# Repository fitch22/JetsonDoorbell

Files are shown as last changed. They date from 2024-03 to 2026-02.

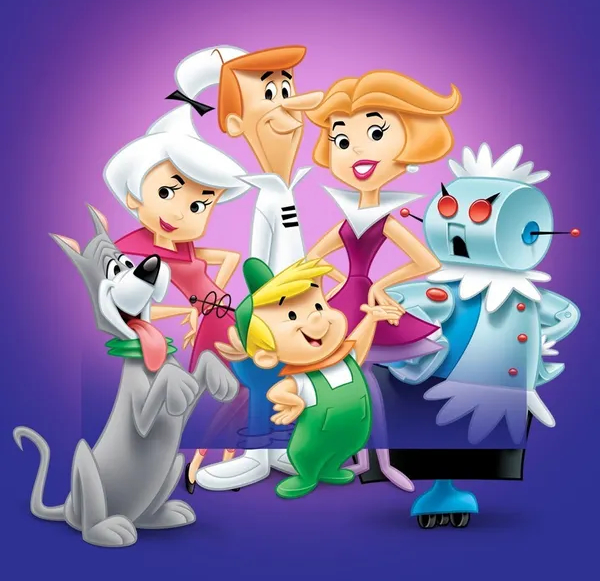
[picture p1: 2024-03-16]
web_root/background.jpg

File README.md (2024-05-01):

# The Jetson Doorbell

This repository has everything you need to get started with your Jetson Doorbell.
The [Getting Started](/fitch22/JetsonDoorbell/docs/GettingStarted.pdf) guide provides details on how to hook it up to replace standard mechanical chime doorbells as well as general operation and troubleshooting.
Several enclosure designs are provided that you can 3D print as is, or modify as necessary for your application.

## Where to find Doorbell Sounds

Here are some links to web sites that have sounds that work well for doorbells:  
[Orange FREE Sounds](https://orangefreesounds.com/)  
[Mixkit](https://mixkit.co/free-sound-effects/doorbell/)  
[Pixabay](https://pixabay.com/sound-effects/search/doorbell/)  
[Zapsplat](https://www.zapsplat.com/)  
Note, several of the sounds you will find to download are in MP3 format and must be converted to WAVE format before using with Jetson Doorbell.
You can convert an MP3 to a WAVE with an online converter such as:  
https://online-audio-converter.com/  
https://cloudconvert.com/audio-converter  
Or you can use an application such as [Audacity](https://www.audacityteam.org/). Audacity can do much more than convert, you can also adjust the tonal balance of the tune which can help with small, less than ideal speakers.

One tune you definitely want to get is the [Jetson's Doorbell](https://orangefreesounds.com/jetsons-doorbell/), just remember to convert it to a WAVE file.

## Building the Firmware

Jetson Doorbell uses an ESP32-S3-N4 module running at 240MHz.
The current version of firmware is 0.1.
It was built with ESP IDF 5.2.1 and uses Mongoose web server 7.13 using VSCODE and the ESP-IDF extension.
Information on how to install the ESP IDF as well as using VSCODE as a development environment can be found [here](https://docs.espressif.com/projects/esp-idf/en/stable/esp32s3/index.html).
Information on how to use the Mongoose web server can be found [here](https://mongoose.ws/).

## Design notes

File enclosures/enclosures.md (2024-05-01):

# Enclosures

In this folder you will find several example designs for enclosing your Jetson Doorbell and a speaker. Each file type has its original source in Solidworks format along with a STEP format and STL. You can print the STL file as is or modify the Solidworks or STEP file as you like.

These designs were all created for some speakers made by Visaton. The Visaton speaker model is part of the file name, for example FR10. I have no affiliation with Visaton, they just happen to make good, economical speakers.

Visaton also makes speaker grills that can be used with their speakers. You might find them more attractive than the 3D printed grills provided here.

For all the enclosures, the design uses M3x4x5 threaded inserts for attaching the lid.
The bosses for mounting the PCBs are expected to be tapped for M3 screws.

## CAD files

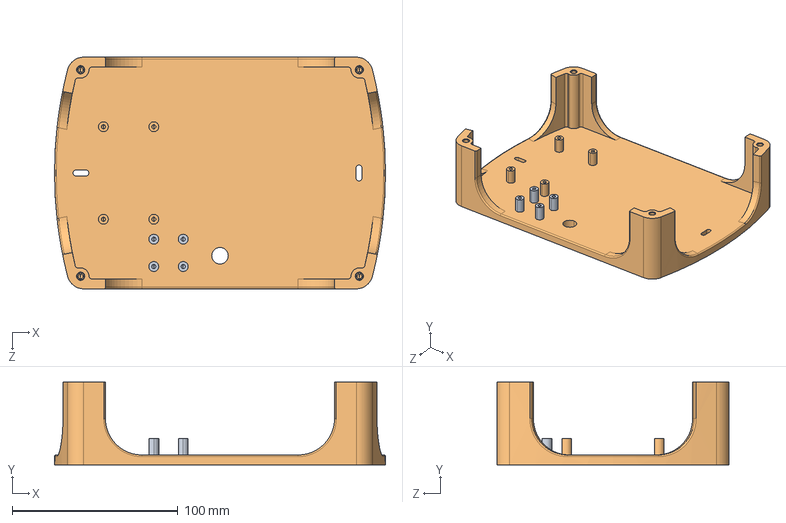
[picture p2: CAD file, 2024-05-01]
enclosures/large box open sides.STEP
200.0 x 50.0 x 140.0 mm

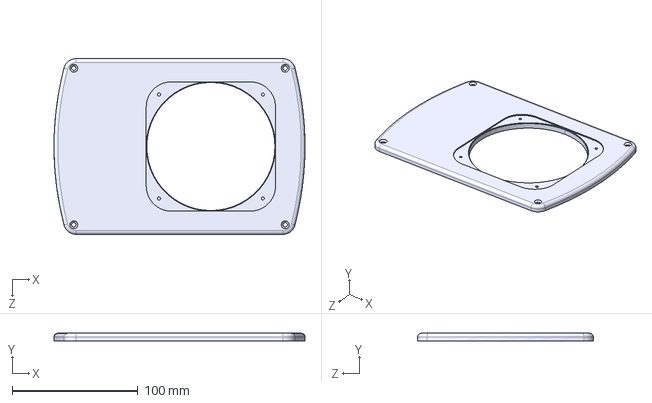
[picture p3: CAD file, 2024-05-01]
enclosures/R10S lid.STEP
199.9 x 6.00 x 140.0 mm

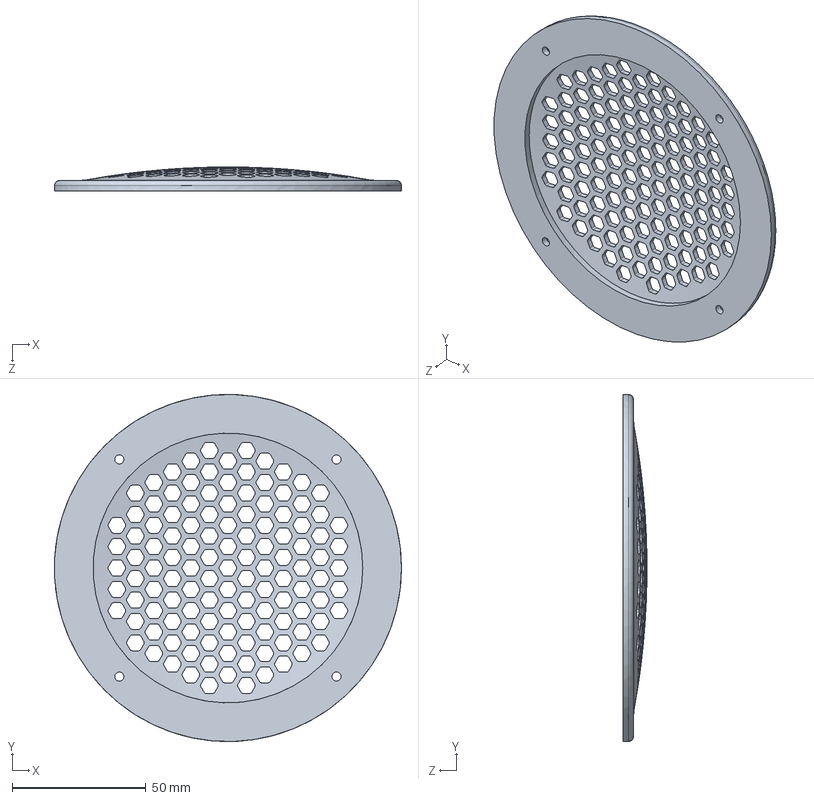
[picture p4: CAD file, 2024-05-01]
enclosures/4in speaker grill.SLDPRT
129.9 x 130.0 x 8.98 mm

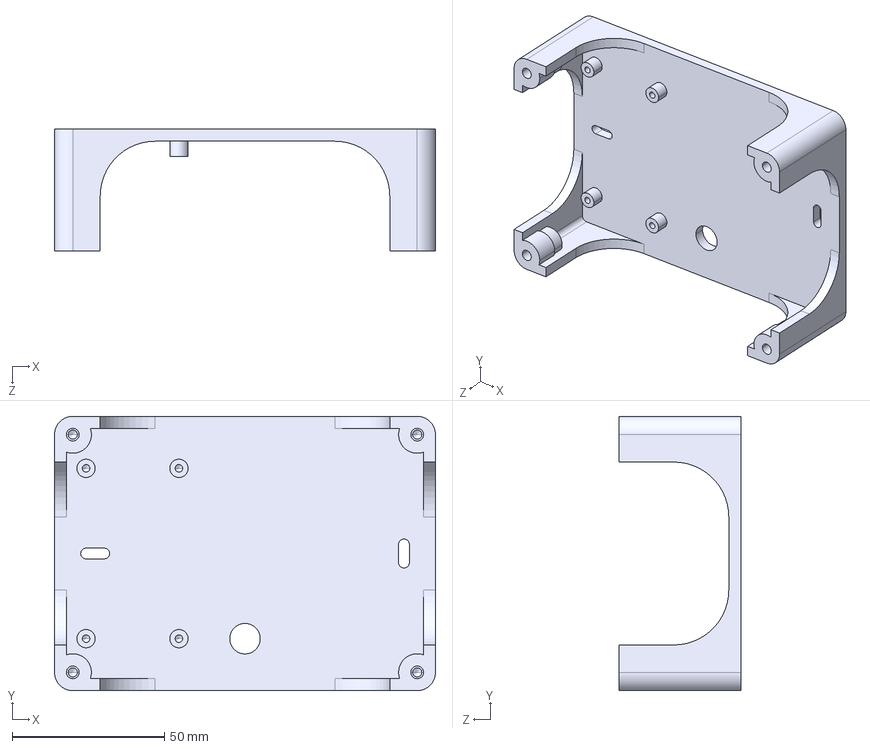
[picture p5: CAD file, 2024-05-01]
enclosures/small box open sides.STEP
125.0 x 90.0 x 40.0 mm

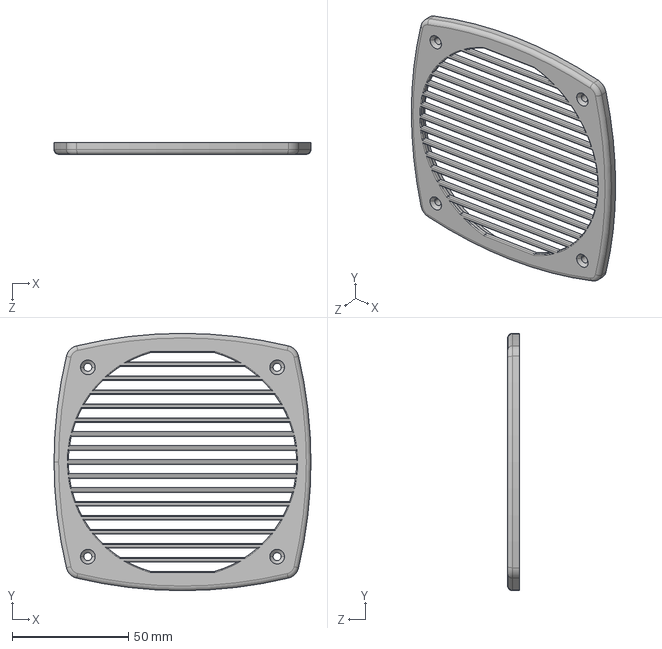
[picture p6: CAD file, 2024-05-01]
enclosures/4in horz speaker grill.STEP
110.4 x 110.5 x 5.00 mm

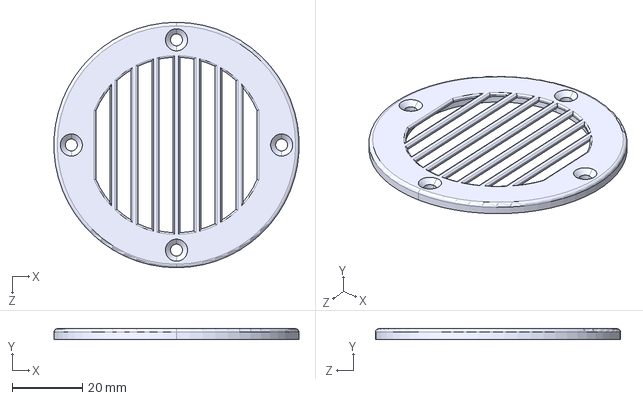
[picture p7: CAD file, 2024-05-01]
enclosures/FRS 5 X grill.STEP
69.9 x 3.00 x 70.0 mm

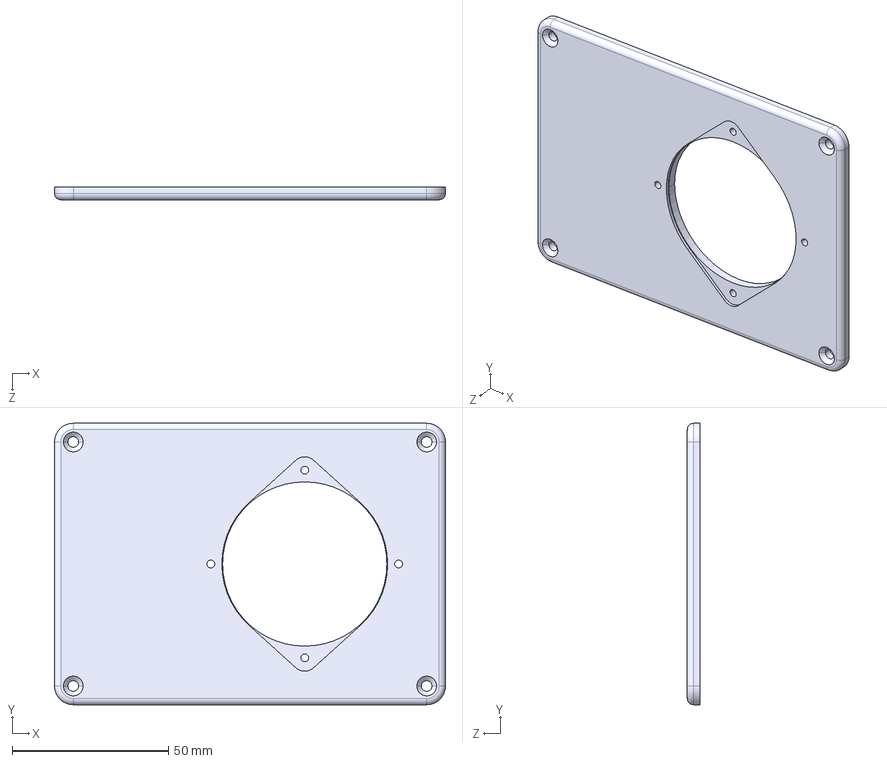
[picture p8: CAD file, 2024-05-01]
enclosures/small box lid.STEP
125.0 x 90.0 x 4.00 mm

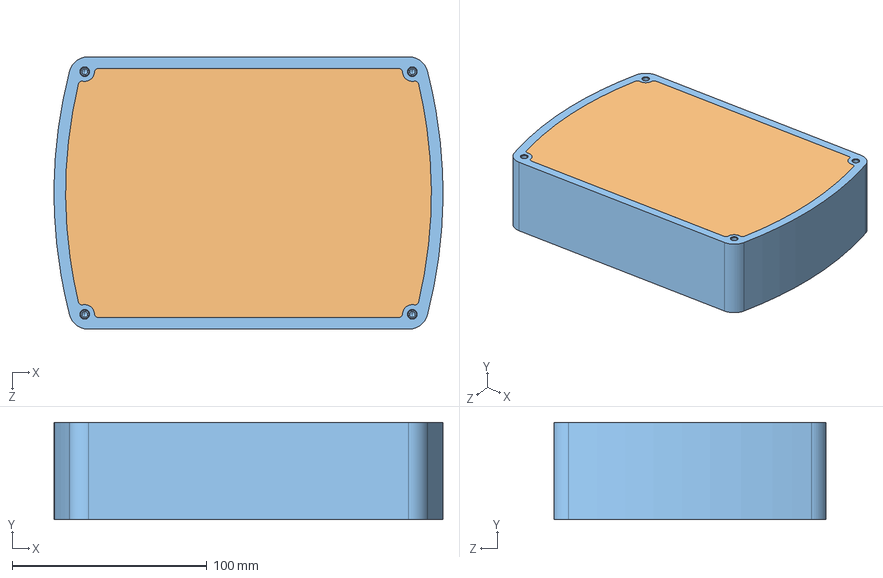
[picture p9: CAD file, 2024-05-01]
enclosures/large box.STEP
199.9 x 50.0 x 140.0 mm

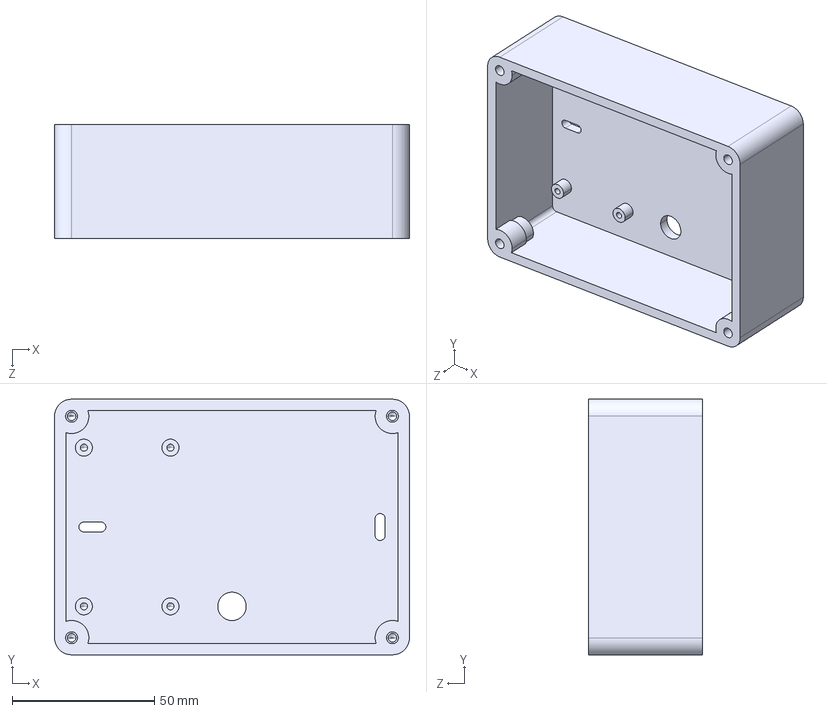
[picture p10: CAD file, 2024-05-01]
enclosures/small box.STEP
125.0 x 90.0 x 40.0 mm

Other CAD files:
enclosures/FR10 lid.STEP
enclosures/4in horz speaker grill.SLDPRT
enclosures/FR10 lid.SLDPRT
enclosures/FRS 5 X grill.SLDPRT
enclosures/R10S lid.SLDPRT
enclosures/large box open sides.SLDPRT
enclosures/large box.SLDPRT
enclosures/large box.STL
enclosures/small box lid.SLDPRT
enclosures/small box open sides.SLDPRT
enclosures/small box open sides.STL
enclosures/small box.SLDPRT
enclosures/small box.STL

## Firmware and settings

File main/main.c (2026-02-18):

#include "driver/gpio.h"
#include "error_blink.h"
#include "freertos/FreeRTOS.h"
#include "freertos/task.h"
#include "global.h"
#include "gpio.h"
#include "i2s.h"
#include "net.h"
#include "sd.h"
#include "sdkconfig.h"
#include "task.h"
#include "wifi.h"
#include <stdint.h>
#include <stdlib.h>
#include <string.h>

extern SemaphoreHandle_t xPlay;

void app_main(void) {
  setup_gpio();

  gpio_set_level(BLINK_PIN, 1);
  vTaskDelay(1000 / portTICK_PERIOD_MS);
  gpio_set_level(BLINK_PIN, 0);

  // if there is no SD card, no point in proceeding
  if (sd_setup() != ESP_OK)
    error_blink(1);

  i2s_setup();

  if (restore_conf() != ESP_OK)
    error_blink(2);

  xTaskCreate(dma_buffer_fill_task, "Fill Task", 4096, NULL, 10, &xFillTask);
  xPlay = xSemaphoreCreateBinary();
  xSemaphoreGive(xPlay);
  xTaskCreate(button1_play_task, "Button1 Task", 4096, NULL, 10, &xButton1Task);
  xTaskCreate(button2_play_task, "Button2 Task", 4096, NULL, 10, &xButton2Task);

  if (wifi_init(wifi_ssid, wifi_pass) != ESP_OK)
    error_blink(3);

  if (start_webserver() != ESP_OK)
    error_blink(4);
  // app_main can return; httpd and all tasks continue running
}

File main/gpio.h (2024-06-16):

// Logic Analyzer pins for debugging
#define LA0 4
#define LA1 5
#define LA2 6
#define LA3 7
#define LA_SEL ((1ULL << LA0) | (1ULL << LA1) | (1ULL << LA2) | (1ULL << LA3))

// Other GPIO
#define BUTTON1_PIN 17 // used for doorbell button1
#define BUTTON1_PIN_SEL (1ULL << BUTTON1_PIN)
#define BUTTON2_PIN 18 // used for doorbell button2
#define BUTTON2_PIN_SEL (1ULL << BUTTON2_PIN)
#define SD_MODE_PIN 14 // enable/disable for MAX98357A
#define SD_MODE_PIN_SEL (1ULL << SD_MODE_PIN)
#define CD_PIN 8 // sd card detect
#define CD_PIN_SEL (1ULL << CD_PIN)
#define BLINK_PIN 13 // Error LED
#define BLINK_PIN_SEL (1ULL << BLINK_PIN)

// SDIO
#define CLK_PIN 9
#define CMD_PIN 10
#define DAT0_PIN 1
#define DAT1_PIN 3
#define DAT2_PIN 12
#define DAT3_PIN 11

// I2S
#define BCLK_PIN 2
#define WS_PIN 38
#define DIN_PIN 21

void setup_gpio(void);

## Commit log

2024-03-16 First upload to github.
    [partition_table.csv, partitions.csv]
2024-03-18 Not require fmt chunk to be first and to skip any chunks not supported.
    [sd.c, task.c]
2024-05-01 Added enclosure design files.
    [4in horz speaker grill.SLDPRT, 4in horz speaker grill.STEP, 4in speaker grill.SLDPRT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]
2024-06-11 Put all GPIP pin definitions in gpio.h for ease of porting to V2.
2024-06-12 Working pinout for V2. This is just the pinout changes for the new PCB, no code changes yet.
2024-06-16 Working version for V2. Added 2nd button input. Lots of duplication for 2nd button. HTML now has 2 sets of tune and volume controls. Volume functions changed to logarithmic from 0 to -40dB.
2024-11-25 Temporary checkin for 0.3 before updating Mongoose.
    [partition_table.csv, partitions.csv]
2025-06-20 Turned off wifi power saving completely. Added
    some more messages for wifi events. Upped the
    revision to 0.6.
2025-06-29 Removed some obsolete code. Tried default power saving with IDF 5.4.2. Updated revision to 0.7a.
2025-10-29 Revert "WIFI now using ESP roaming app."
    This reverts commit d6ae326c00854953f0e573e1adf5084b310b2819.
    [main.c]
2026-02-18 Eliminated Mongoose
    New version with no mongoose dependencies. Web files are embedded into flash.
    [partitions.csv]
2026-02-18 Web File cleanup
    Improvements to web files. Removed password printing from serial logs.
